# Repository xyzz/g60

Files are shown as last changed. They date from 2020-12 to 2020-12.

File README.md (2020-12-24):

# g60

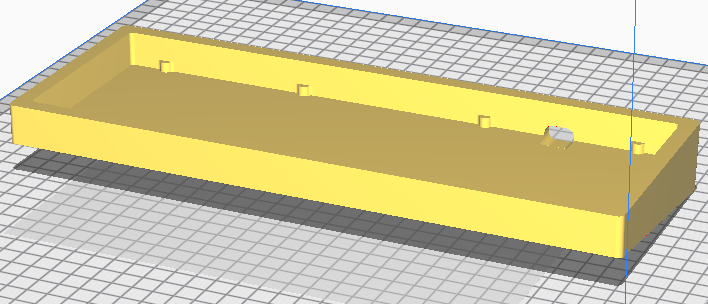
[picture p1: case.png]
case STL


A simple 3d-printable oring gasket keyboard.

## Known issues

Depending on 3d print tolerances, plate and PCB edges might scratch against the corners of the case. Ideally, the outlines of both should be reduced a little bit. Unfortunately, these changes will not be done as a result of me losing interest in the project due to availability of [Bakeneko](https://github.com/kkatano/bakeneko-60-aluminum-case).

## Compatibility

The PCB is not compatible with other cases due to custom mounting point cutouts and USB position. In turn, the case is also not compatible with any third-party PCBs.

## Oring size

Around 180mm ID and 3.5mm CS, for example  AS568-263 should work fine.

## Machinability

The case should be machinable, however it was not tested and I cannot suggest getting it machined due to extremely simplistic design (ie just make a Bakeneko instead).

## License

This project is licensed under [CC0](https://creativecommons.org/share-your-work/public-domain/cc0/), see the LICENSE file for more details, or [tldrlegal.com](https://tldrlegal.com/license/creative-commons-cc0-1.0-universal) for a summary.

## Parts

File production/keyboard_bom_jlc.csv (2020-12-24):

Comment | Designator | Footprint | LCSC Part #
100n | C1,C10,C8,C7 | C_0603_1608Metric | C14663
4.7u | C4,C2 | C_0603_1608Metric | C19666
1u | C5,C6,C3 | C_0603_1608Metric | C15849
10n | C9 | C_0603_1608Metric | C57112
D | D_0,D_1,D_2,D_3,D_4,D_5,D_6,D_7,D_8,D_9,D_10,D_11,D_12,D_13,D_14,D_15,D_16,D_17,D_18,D_19,D_20,D_21,D_22,D_23,D_24,D_25,D_26,D_27,D_28,D_29,D_30,D_31,D_32,D_33,D_34,D_35,D_36,D_37,D_38,D_39,D_40,D_41,D_42,D_43,D_44,D_45,D_46,D_47,D_48,D_49,D_50,D_51,D_52,D_53,D_54,D_55,D_56,D_57,D_58,D_59,D_60,D_61,D_62,D_63 | D_SOD-123 | C81598
500mA | F1 | Fuse_1206_3216Metric | C369159
10k | R1 | R_0603_1608Metric | C25804
5.1k | R2,R3 | R_0603_1608Metric | C23186
RESET | SW1 | SW_SPST_TL3342 | C318884
BOOT | SW2 | SW_SPST_TL3342 | C318884
SRV05-4 | U1 | SOT-23-6 | C85364
STM32F072C8Ux | U2 | QFN-48-1EP_7x7mm_P0.5mm_EP5.6x5.6mm | C92504
XC6206P332MR | U3 | SOT-23 | C5446

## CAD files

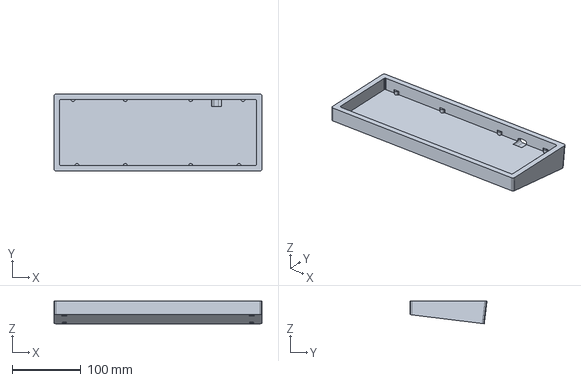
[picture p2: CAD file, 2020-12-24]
case.stp
302.7 x 112.2 x 32.8 mm

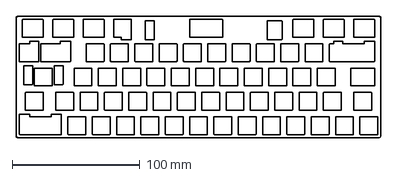
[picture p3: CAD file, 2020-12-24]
vector/plate-outline.dxf
285.8 x 95.2 mm

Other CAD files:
production/case.stl

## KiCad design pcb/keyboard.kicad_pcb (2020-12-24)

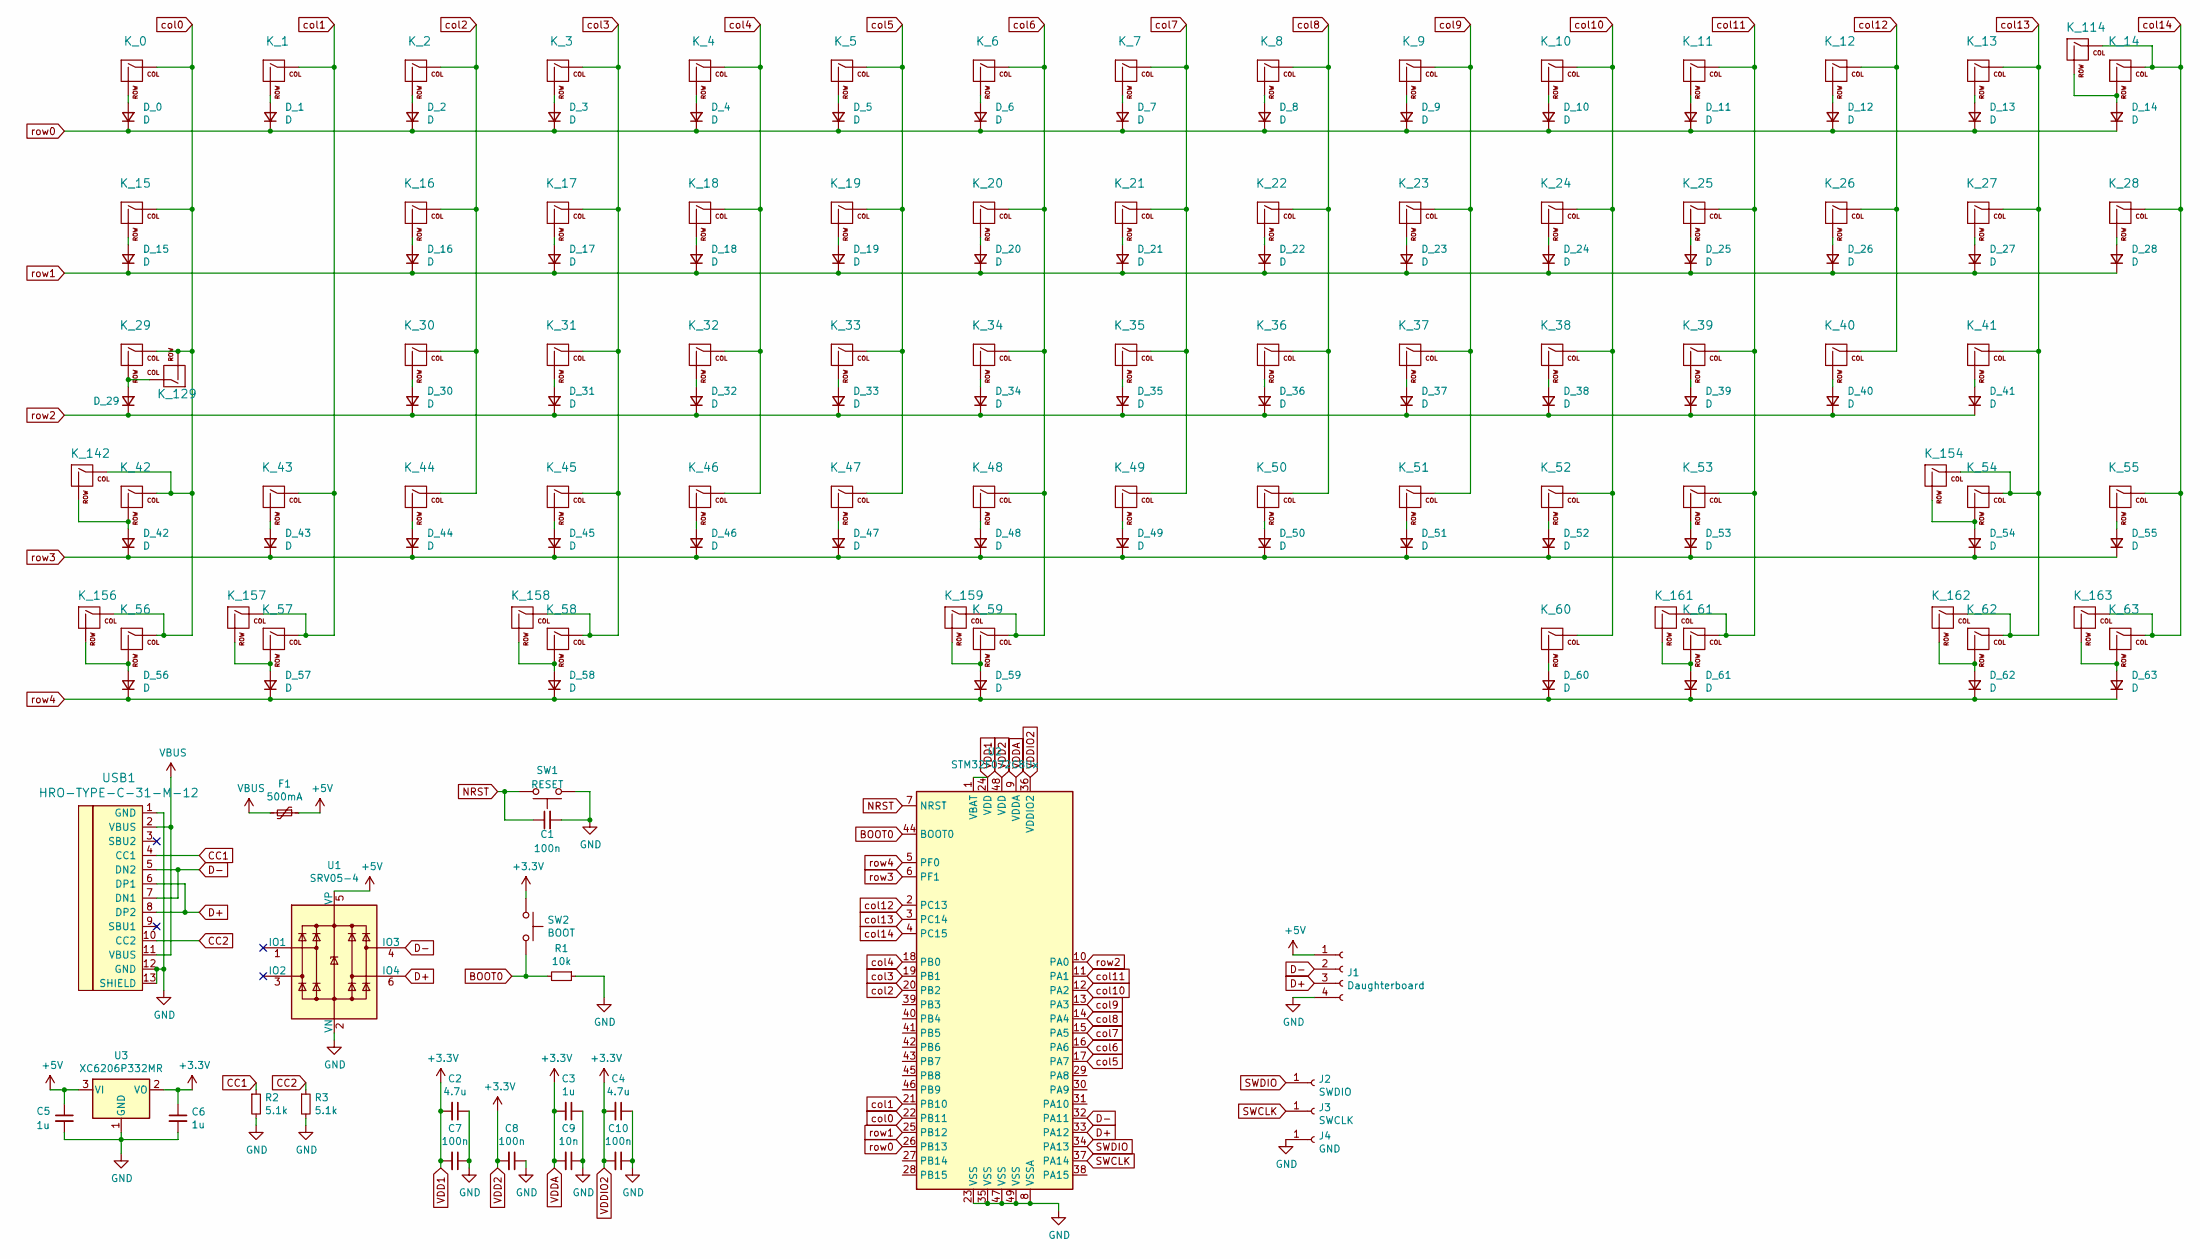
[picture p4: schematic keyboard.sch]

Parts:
C1, C7, C8, C10: 100n; C_0603_1608Metric; LCSC C14663
C2, C4: 4.7u; C_0603_1608Metric; LCSC C19666
C3, C5, C6: 1u; C_0603_1608Metric; LCSC C15849
C9: 10n; C_0603_1608Metric; LCSC C57112
D_0, D_1, D_2, D_3, D_4, D_5, D_6, D_7, D_8, D_9, D_10, D_11, D_12, D_13, D_14, D_15, D_16, D_17, D_18, D_19, D_20, D_21, D_22, D_23, D_24, D_25, D_26, D_27, D_28, D_29, D_30, D_31, D_32, D_33, D_34, D_35, D_36, D_37, D_38, D_39, D_40, D_41, D_42, D_43, D_44, D_45, D_46, D_47, D_48, D_49, D_50, D_51, D_52, D_53, D_54, D_55, D_56, D_57, D_58, D_59, D_60, D_61, D_62, D_63: D; D_SOD-123; LCSC C81598
F1: 500mA; Fuse_1206_3216Metric; LCSC C369159
J1: Daughterboard; JST_SH_SM04B-SRSS-TB_1x04-1MP_P1.00mm_Horizontal
J2: SWDIO; TestPoint_Pad_D1.5mm
J3: SWCLK; TestPoint_Pad_D1.5mm
J4: GND; TestPoint_Pad_D1.5mm
K_0, K_1, K_2, K_3, K_4, K_5, K_6, K_7, K_8, K_9, K_10, K_11, K_12, K_13, K_14, K_16, K_17, K_18, K_19, K_20, K_21, K_22, K_23, K_24, K_25, K_26, K_27, K_30, K_31, K_32, K_33, K_34, K_35, K_36, K_37, K_38, K_39, K_40, K_43, K_44, K_45, K_46, K_47, K_48, K_49, K_50, K_51, K_52, K_53, K_55: KEYSW; MXOnly-1U-NoLED
K_15, K_28: KEYSW; MXOnly-1.5U-NoLED
K_29: Regular; MXOnly-1.75U-NoLED
K_41: KEYSW; MXOnly-2.25U-NoLED
K_42: KEYSW; MXOnly-1.25U-NoLED
K_54: KEYSW; MXOnly-1.75U-NoLED
K_56, K_57, K_58, K_60, K_61, K_62, K_63: 1.25u; MXOnly-1.25U-NoLED
K_59: 6.25u; MXOnly-6.25U-ReversedStabilizers-NoLED
K_114: MX-NoLED; MXOnly-2U-NoLED
K_129: Stepped; MXOnly-1.25U-NoLED
K_142: MX-NoLED; MXOnly-2.25U-NoLED
K_154: MX-NoLED; MXOnly-2.75U-NoLED
K_156, K_158, K_161, K_163: 1.5u; MXOnly-1.5U-NoLED
K_157, K_162: 1u; MXOnly-1U-NoLED
K_159: 7u; MXOnly-7U-ReversedStabilizers-NoLED
R1: 10k; R_0603_1608Metric; LCSC C25804
R2, R3: 5.1k; R_0603_1608Metric; LCSC C23186
SW1: RESET; SW_SPST_TL3342; LCSC C318884
SW2: BOOT; SW_SPST_TL3342; LCSC C318884
U1: SRV05-4; SOT-23-6; LCSC C85364
U2: STM32F072C8Ux; QFN-48-1EP_7x7mm_P0.5mm_EP5.6x5.6mm; LCSC C92504
U3: XC6206P332MR; SOT-23; LCSC C5446
USB1: HRO-TYPE-C-31-M-12

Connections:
+5V: C5.1, F1.1, J1.1, U1.5 (VP), U3.3 (VI)
BOOT0: R1.2, SW2.2, U2.44 (BOOT0)
CC1: R2.1, USB1.4 (CC1)
CC2: R3.1, USB1.10 (CC2)
D+: J1.3, U1.6 (IO4), U2.33 (PA12), USB1.6 (DP1), USB1.8 (DP2)
D-: J1.2, U1.4 (IO3), U2.32 (PA11), USB1.5 (DN2), USB1.7 (DN1)
GND: C1.2, C2.1, C3.1, C4.1, C5.2, C6.2, C7.1, C8.1, C9.1, C10.1, J1.4, J4.1, R1.1, R2.2, R3.2, SW1.1, U1.2 (VN), U2.8 (VSSA), U2.23 (VSS), U2.35 (VSS), U2.47 (VSS), U2.49 (VSS), U3.1 (GND), USB1.1 (GND), USB1.12 (GND), USB1.13 (SHIELD)
NRST: C1.1, SW1.2, U2.7 (NRST)
unnamed: D_0.2 (A), K_0.2 (ROW)
unnamed: D_1.2 (A), K_1.2 (ROW)
unnamed: D_2.2 (A), K_2.2 (ROW)
unnamed: D_3.2 (A), K_3.2 (ROW)
unnamed: D_4.2 (A), K_4.2 (ROW)
unnamed: D_5.2 (A), K_5.2 (ROW)
unnamed: D_6.2 (A), K_6.2 (ROW)
unnamed: D_7.2 (A), K_7.2 (ROW)
unnamed: D_8.2 (A), K_8.2 (ROW)
unnamed: D_9.2 (A), K_9.2 (ROW)
unnamed: D_10.2 (A), K_10.2 (ROW)
unnamed: D_11.2 (A), K_11.2 (ROW)
unnamed: D_12.2 (A), K_12.2 (ROW)
unnamed: D_13.2 (A), K_13.2 (ROW)
unnamed: D_14.2 (A), K_14.2 (ROW), K_114.2 (ROW)
unnamed: D_15.2 (A), K_15.2 (ROW)
unnamed: D_16.2 (A), K_16.2 (ROW)
unnamed: D_17.2 (A), K_17.2 (ROW)
unnamed: D_18.2 (A), K_18.2 (ROW)
unnamed: D_19.2 (A), K_19.2 (ROW)
unnamed: D_20.2 (A), K_20.2 (ROW)
unnamed: D_21.2 (A), K_21.2 (ROW)
unnamed: D_22.2 (A), K_22.2 (ROW)
unnamed: D_23.2 (A), K_23.2 (ROW)
unnamed: D_24.2 (A), K_24.2 (ROW)
unnamed: D_25.2 (A), K_25.2 (ROW)
unnamed: D_26.2 (A), K_26.2 (ROW)
unnamed: D_27.2 (A), K_27.2 (ROW)
unnamed: D_28.2 (A), K_28.2 (ROW)
unnamed: D_29.2 (A), K_29.2 (ROW), K_129.1 (COL)
unnamed: D_30.2 (A), K_30.2 (ROW)
unnamed: D_31.2 (A), K_31.2 (ROW)
unnamed: D_32.2 (A), K_32.2 (ROW)
unnamed: D_33.2 (A), K_33.2 (ROW)
unnamed: D_34.2 (A), K_34.2 (ROW)
unnamed: D_35.2 (A), K_35.2 (ROW)
unnamed: D_36.2 (A), K_36.2 (ROW)
unnamed: D_37.2 (A), K_37.2 (ROW)
unnamed: D_38.2 (A), K_38.2 (ROW)
unnamed: D_39.2 (A), K_39.2 (ROW)
unnamed: D_40.2 (A), K_40.2 (ROW)
unnamed: D_41.2 (A), K_41.2 (ROW)
unnamed: D_42.2 (A), K_42.2 (ROW), K_142.2 (ROW)
unnamed: D_43.2 (A), K_43.2 (ROW)
unnamed: D_44.2 (A), K_44.2 (ROW)
unnamed: D_45.2 (A), K_45.2 (ROW)
unnamed: D_46.2 (A), K_46.2 (ROW)
unnamed: D_47.2 (A), K_47.2 (ROW)
unnamed: D_48.2 (A), K_48.2 (ROW)
unnamed: D_49.2 (A), K_49.2 (ROW)
unnamed: D_50.2 (A), K_50.2 (ROW)
unnamed: D_51.2 (A), K_51.2 (ROW)
unnamed: D_52.2 (A), K_52.2 (ROW)
unnamed: D_53.2 (A), K_53.2 (ROW)
unnamed: D_54.2 (A), K_54.2 (ROW), K_154.2 (ROW)
unnamed: D_55.2 (A), K_55.2 (ROW)
unnamed: D_56.2 (A), K_56.2 (ROW), K_156.2 (ROW)
unnamed: D_57.2 (A), K_57.2 (ROW), K_157.2 (ROW)
unnamed: D_58.2 (A), K_58.2 (ROW), K_158.2 (ROW)
unnamed: D_59.2 (A), K_59.2 (ROW), K_159.2 (ROW)
unnamed: D_60.2 (A), K_60.2 (ROW)
unnamed: D_61.2 (A), K_61.2 (ROW), K_161.2 (ROW)
unnamed: D_62.2 (A), K_62.2 (ROW), K_162.2 (ROW)
unnamed: D_63.2 (A), K_63.2 (ROW), K_163.2 (ROW)
SWCLK: J3.1, U2.37 (PA14)
SWDIO: J2.1, U2.34 (PA13)
VBUS: F1.2, USB1.2 (VBUS), USB1.11 (VBUS)
VDD1: C2.2, C3.2, C4.2, C6.1, C7.2, C8.2, C9.2, C10.2, SW2.1, U2.1 (VBAT), U2.9 (VDDA), U2.24 (VDD), U2.36 (VDDIO2), U2.48 (VDD), U3.2 (VO)
col0: K_0.1 (COL), K_15.1 (COL), K_29.1 (COL), K_42.1 (COL), K_56.1 (COL), K_129.2 (ROW), K_142.1 (COL), K_156.1 (COL), U2.22 (PB11)
col1: K_1.1 (COL), K_43.1 (COL), K_57.1 (COL), K_157.1 (COL), U2.21 (PB10)
col2: K_2.1 (COL), K_16.1 (COL), K_30.1 (COL), K_44.1 (COL), U2.20 (PB2)
col3: K_3.1 (COL), K_17.1 (COL), K_31.1 (COL), K_45.1 (COL), K_58.1 (COL), K_158.1 (COL), U2.19 (PB1)
col4: K_4.1 (COL), K_18.1 (COL), K_32.1 (COL), K_46.1 (COL), U2.18 (PB0)
col5: K_5.1 (COL), K_19.1 (COL), K_33.1 (COL), K_47.1 (COL), U2.17 (PA7)
col6: K_6.1 (COL), K_20.1 (COL), K_34.1 (COL), K_48.1 (COL), K_59.1 (COL), K_159.1 (COL), U2.16 (PA6)
col7: K_7.1 (COL), K_21.1 (COL), K_35.1 (COL), K_49.1 (COL), U2.15 (PA5)
col8: K_8.1 (COL), K_22.1 (COL), K_36.1 (COL), K_50.1 (COL), U2.14 (PA4)
col9: K_9.1 (COL), K_23.1 (COL), K_37.1 (COL), K_51.1 (COL), U2.13 (PA3)
col10: K_10.1 (COL), K_24.1 (COL), K_38.1 (COL), K_52.1 (COL), K_60.1 (COL), U2.12 (PA2)
col11: K_11.1 (COL), K_25.1 (COL), K_39.1 (COL), K_53.1 (COL), K_61.1 (COL), K_161.1 (COL), U2.11 (PA1)
col12: K_12.1 (COL), K_26.1 (COL), K_40.1 (COL), U2.2 (PC13)
col13: K_13.1 (COL), K_27.1 (COL), K_41.1 (COL), K_54.1 (COL), K_62.1 (COL), K_154.1 (COL), K_162.1 (COL), U2.3 (PC14)
col14: K_14.1 (COL), K_28.1 (COL), K_55.1 (COL), K_63.1 (COL), K_114.1 (COL), K_163.1 (COL), U2.4 (PC15)
row0: D_0.1 (K), D_1.1 (K), D_2.1 (K), D_3.1 (K), D_4.1 (K), D_5.1 (K), D_6.1 (K), D_7.1 (K), D_8.1 (K), D_9.1 (K), D_10.1 (K), D_11.1 (K), D_12.1 (K), D_13.1 (K), D_14.1 (K), U2.26 (PB13)
row1: D_15.1 (K), D_16.1 (K), D_17.1 (K), D_18.1 (K), D_19.1 (K), D_20.1 (K), D_21.1 (K), D_22.1 (K), D_23.1 (K), D_24.1 (K), D_25.1 (K), D_26.1 (K), D_27.1 (K), D_28.1 (K), U2.25 (PB12)
row2: D_29.1 (K), D_30.1 (K), D_31.1 (K), D_32.1 (K), D_33.1 (K), D_34.1 (K), D_35.1 (K), D_36.1 (K), D_37.1 (K), D_38.1 (K), D_39.1 (K), D_40.1 (K), D_41.1 (K), U2.10 (PA0)
row3: D_42.1 (K), D_43.1 (K), D_44.1 (K), D_45.1 (K), D_46.1 (K), D_47.1 (K), D_48.1 (K), D_49.1 (K), D_50.1 (K), D_51.1 (K), D_52.1 (K), D_53.1 (K), D_54.1 (K), D_55.1 (K), U2.6 (PF1)
row4: D_56.1 (K), D_57.1 (K), D_58.1 (K), D_59.1 (K), D_60.1 (K), D_61.1 (K), D_62.1 (K), D_63.1 (K), U2.5 (PF0)

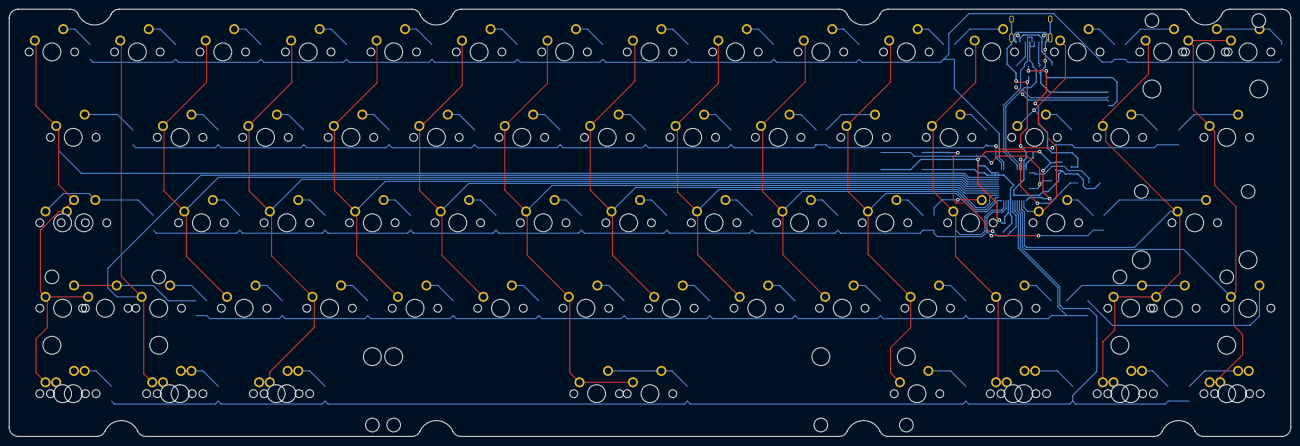
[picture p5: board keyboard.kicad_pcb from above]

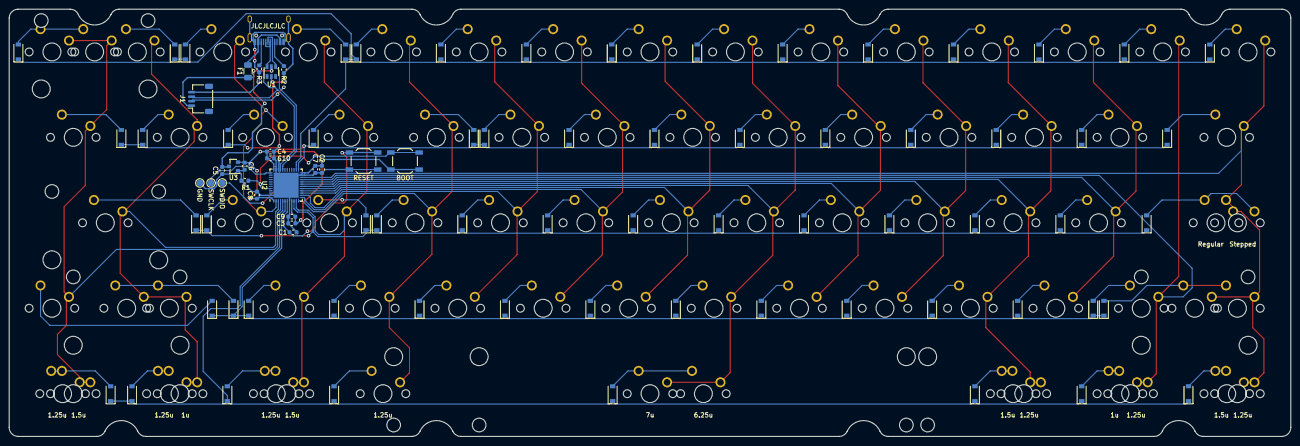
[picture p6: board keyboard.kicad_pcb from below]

Board: 2 copper layers, 285.8 x 95.3 mm, 163 parts (88 on the bottom side), 96 nets.
